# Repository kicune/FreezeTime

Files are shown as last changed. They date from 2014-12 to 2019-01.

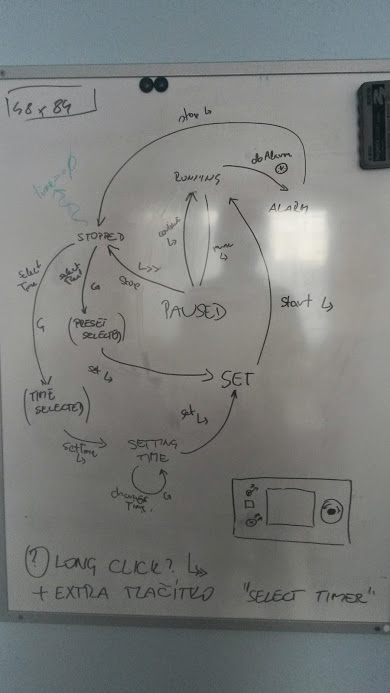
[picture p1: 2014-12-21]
FreezeTime_stateDiag.jpg

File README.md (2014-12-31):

FreezeTime
==========

Arduino - based kitchen multi timer.

This is a simple project I started to provide our kitchen with the ability to track two (but, in a theory, with many more!) kitchen timers running simultaneously. You know, to satistfy your coffee brewing needs, when your SO is busy timing the dinner or what not.

My first approach was to buy another kitchen timer, but after some thought I decided that would be seriously uncool.
This is the second approach. :)

Some basic info:
- the schema utilizes LCD display from Nokia 5110. It's very cheap, it's very bright and easy to work with. But beware - it runs on 3V only, so if you try to reprogramm the microprocessor using USB, you MIGHT destroy it (I tried it, however, and mine survived quite a prolonged exposure to 5V). Reprogramming using external programmer (or simple 5V -> 3V level shifter) is preferred.
- the board for Eagle is 2-sided, which makes things slightly more complicated. There may be ways how to rearrange the board and make it single sided, but I wanted to have controls on the one side of the board and batteries & connector on the other side. The board is routed for a simple CNC router with 0.3 engraving V tip.
- the schematics is pretty straighforward, with microprocessor, binary encoder, LCD and switch. The only thing that is not absolutely basic here is the charge pump to sound the buzzer. I did not found a good buzzer with reasonable 3V input, so I use a simple 7660 charge pump to boost the voltage to 5V. Also, MOSFET is used to drive the buzzer, as it can sink a reasonable amount of current that would not be healthy for ATMEL / Arduino pins.
- if you decide to change the tone the buzzer beeps, beware - I encountered strange behaviour (microprocessor resetting itself...) with some frequencies.

- STL file for 3d printed enclosure will be added later.

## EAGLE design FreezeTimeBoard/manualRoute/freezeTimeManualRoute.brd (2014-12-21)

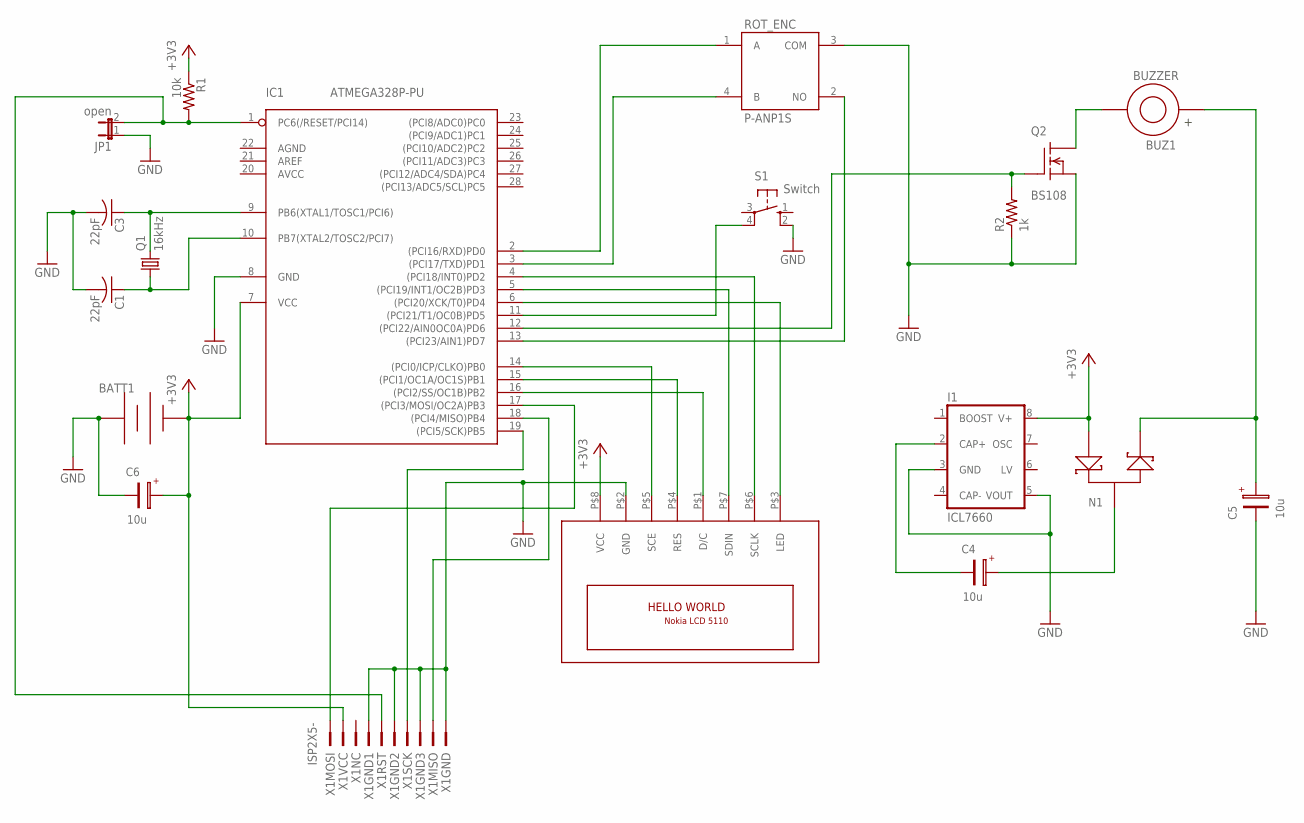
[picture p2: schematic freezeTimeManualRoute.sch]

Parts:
BATT1: 3VBATTERY; BH241-3A
BUZ1: BUZZER; AL1210MTE-P5R
C1, C3: 22pF; C1206
C4, C5, C6: 10u; C/6032-28R
I1: ICL7660; SO08
IC1: ATMEGA328P-PU; DIL28-3
JP1: open; JP1
LCD1: LCD_NOKIA5110; LCM5110_W
N1: BAT54S; SOT23
Q1: 16kHz; HC49U70
Q2: BS108; TO92-INLINE
R1: 10k; R1206
R2: 1k; R1206
ROT_ENC: P-ANP1S
S1: Switch; TACTS-24N
X1: ISP2X5-; PAK100/2500-10

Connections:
+3V3: BATT1.+, C6.+, I1.8 (V+), IC1.7 (VCC), LCD1.P$8 (VCC), N1.1, R1.1, X1.2
GND: BATT1.-, C1.2, C3.2, C5.-, C6.-, I1.3 (GND), I1.5 (VOUT), IC1.8 (GND), JP1.1, LCD1.P$2 (GND), Q2.3 (S), R2.1, ROT_ENC.3 (COM), S1.2 (S1), X1.4, X1.6, X1.8, X1.10
unnamed: C3.1, IC1.9 (PB6(XTAL1/TOSC1/PCI6)), Q1.2
unnamed: C1.1, IC1.10 (PB7(XTAL2/TOSC2/PCI7)), Q1.1
unnamed: IC1.13 ((PCI23/AIN1)PD7), ROT_ENC.2 (NO)
unnamed: IC1.1 (PC6(/RESET/PCI14)), JP1.2, R1.2, X1.5
unnamed: IC1.2 ((PCI16/RXD)PD0), ROT_ENC.1 (A)
unnamed: IC1.18 ((PCI4/MISO)PB4), X1.9
unnamed: IC1.3 ((PCI17/TXD)PD1), ROT_ENC.4 (B)
unnamed: IC1.15 ((PCI1/OC1A/OC1S)PB1), LCD1.P$4 (RES)
unnamed: IC1.14 ((PCI0/ICP/CLKO)PB0), LCD1.P$5 (SCE)
unnamed: IC1.16 ((PCI2/SS/OC1B)PB2), LCD1.P$1 (D/C)
unnamed: IC1.17 ((PCI3/MOSI/OC2A)PB3), X1.1
unnamed: IC1.11 ((PCI21/T1/OC0B)PD5), S1.4 (P1)
unnamed: IC1.6 ((PCI20/XCK/T0)PD4), LCD1.P$3 (LED)
unnamed: BUZ1.2, Q2.1 (D)
unnamed: IC1.19 ((PCI5/SCK)PB5), X1.7
unnamed: IC1.12 ((PCI22/AIN0OC0A)PD6), Q2.2 (G), R2.2
unnamed: IC1.5 ((PCI19/INT1/OC2B)PD3), LCD1.P$7 (SDIN)
unnamed: IC1.4 ((PCI18/INT0)PD2), LCD1.P$6 (SCLK)
unnamed: C4.-, I1.2 (CAP+)
unnamed: C4.+, N1.3
unnamed: BUZ1.1 (+), C5.+, N1.2

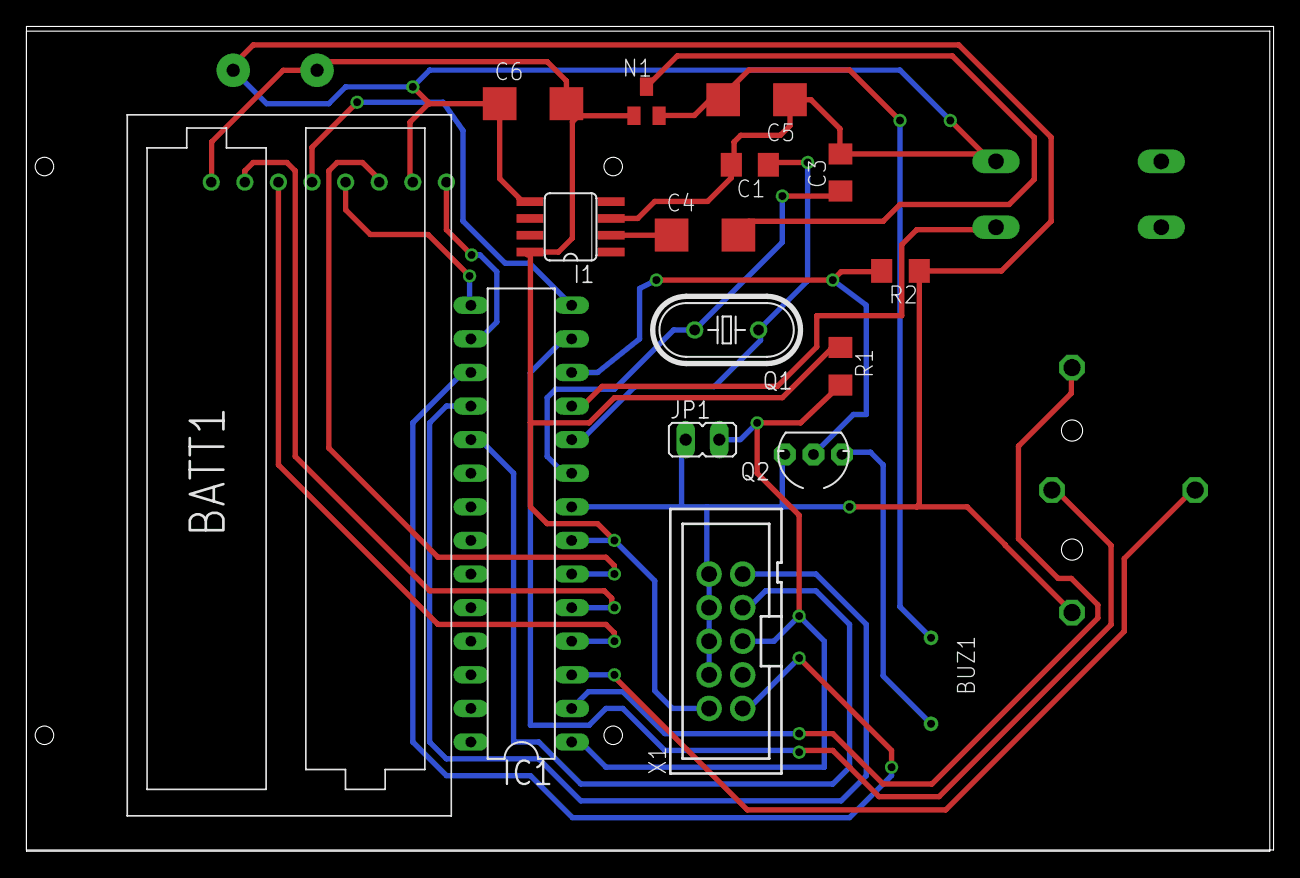
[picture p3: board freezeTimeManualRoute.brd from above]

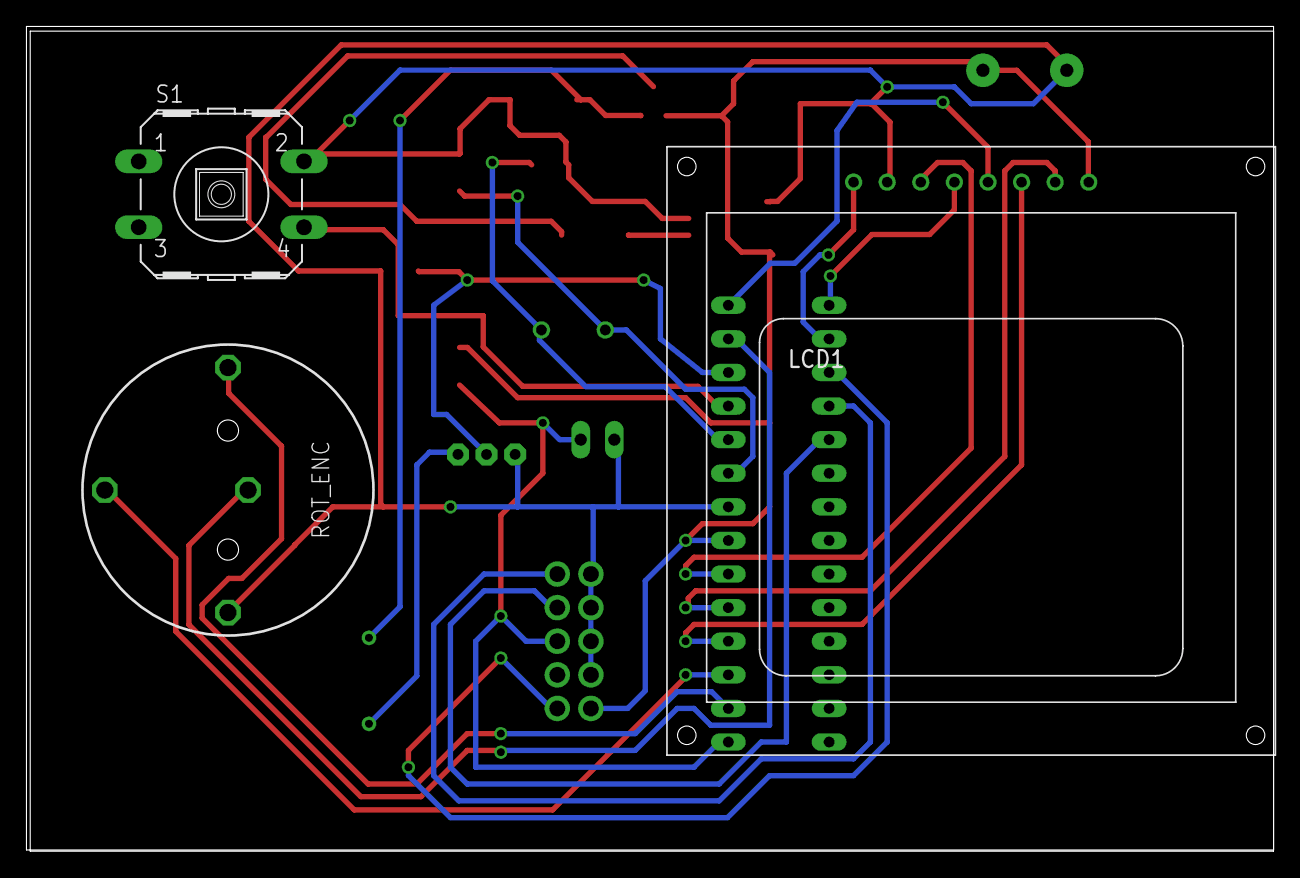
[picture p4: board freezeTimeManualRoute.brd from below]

Board: 2 copper layers, 94.3 x 62.3 mm, 19 parts (3 on the bottom side), 23 nets.

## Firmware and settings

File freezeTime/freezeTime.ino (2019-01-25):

#include <U8glib.h>
#include <Encoder.h>
#include <OneButton.h>
//#include <SoftwareSerial.h>
#include "freezeTimer.h"
#include "pitches.h"
#include "Ports.h"

/*
*    Zapojeni:
 *    
 *    Display: VSS:GND, VDD:+5V , RS:10, R/W:11, E:13, PSB:GND, A:+5V, K:GND
 *    Encoder: A:2, B:3, COM:GND, N0:7
 *    Beeper: -:GND, S:12
 *    Prepinac timeru: -:GND, S:8
 *    
 */

#define ENC_PIN_A    2
#define ENC_PIN_B    3
#define ENC_PIN_SWITCH    7
#define BEEP_PIN     6
#define SWITCH_PIN   5

#define SCK_PIN      13
#define LCD_LED_PIN  4

//U8GLIB_ST7920_128X64_1X u8g(SCK_PIN);

//5110 hw SPI: U8GLIB_PCD8544(sck, mosi, cs, a0 [, reset])
//5110 sw SPI: U8GLIB_PCD8544(cs, a0 [, reset])
//led sck mosi d/c(a0) rst sce(c/s) gnd vcc
//U8GLIB_PCD8544 u8g(12, 11, 8, 10, 9);
U8GLIB_PCD8544 u8g(0, 1, 8, 10, 9); 

#define NUM_OF_TIMERS    2
FreezeTimer timers[] = {            //an array of timers
    FreezeTimer("Timer 1", 0, 0, 0, &u8g),
    FreezeTimer("Timer 2", 0, 0, TIMER_HEIGHT, &u8g)
 };


//variables and defines to process encoder clicks
#define ENC_CLICKED  1
#define ENC_PRESSED  2
//#define ENC_PRESS_DELAY    500    // how long must the long press be, in ms.

//how long timer stays on when nothing is happening (in ms.)
#define TIMER_OFF_DELAY    10000

//pause between two alarm beeps, in millis.
#define ALARM_PAUSE    500

byte encoderClicked = 0;
byte risingFalling = 0;  
boolean isDisplayOn = false;

FreezeTimer *activeTimer = NULL;     //a pointer to the timer that currently receives an input
byte activeTimerIdx;

char buf[24];

Encoder encoder(ENC_PIN_A, ENC_PIN_B);
long encPrevValue = 0;
long encValue = 0;

OneButton btnSwitch(SWITCH_PIN, true);      //Switch timer button
OneButton btnEncoder(ENC_PIN_SWITCH, true); //encoder button

//timestamp of the last press
unsigned long lastActivityTimestamp = 0;
//sleeping flag
boolean isSleeping = false;

void draw(void) {
    u8g.setColorIndex(1);
    u8g.drawFrame(0,0,84, 48);
//    u8g.setFont(u8g_font_unifont);  
    u8g.setFont(u8g_font_7x13B);
    u8g.setFontRefHeightExtendedText();
    u8g.setFontPosTop();    
}

//put the FreezeTimer to sleep
void sleep() {
     //turn the lcd light off
    displayOff();
    //put the display to sleep
    u8g.sleepOff();
    //put ATMEL to sleep
    Sleepy::powerDown();    
}

void wakeUp() {
    //ATMEL will wake up itself with an interrupt
    //wake the display
    u8g.sleepOn();
    displayOn();
    
}

void displayOn() {
    digitalWrite(LCD_LED_PIN, 1);
    isDisplayOn = true;
}

void displayOff() {
    digitalWrite(LCD_LED_PIN, 0);
    isDisplayOn = false;
}

void timerSwitch() {
    lastActivityTimestamp = millis();
    //if the lcd backlight is off, turn it on
    if(!isDisplayOn) displayOn();
    
    //deactivate current timer
    activeTimer->setActive(false);
    
    //switch to the next timer
    if(++activeTimerIdx > NUM_OF_TIMERS - 1) {
        activeTimerIdx = 0;
    }   
    
    //activate the next timer
    activeTimer = &timers[activeTimerIdx];
    activeTimer->setActive(true);
}

void encoderClick() {
    //confirm click by beeping
    tone(BEEP_PIN, NOTE_C4, 70);
    //if the lcd backlight is off, turn it on
    if(!isDisplayOn) displayOn();
    
    lastActivityTimestamp = millis();
    
    activeTimer->click();    
}

void encoderPress() {
    //confirm click by long beep
    tone(BEEP_PIN, NOTE_C4, 210);
    lastActivityTimestamp = millis();
    activeTimer->longClick();
}

void soundAlarm() {
    static unsigned long lastAlarmMillis = 0; //timestamp of the last alarm sounding

    //sound the alarm - verify the delay since the last alarm sound and if it's bigger than the ALARM_PAUSE, sound the beeper
    if(millis() - lastAlarmMillis > ALARM_PAUSE) {
        tone(BEEP_PIN, NOTE_C5, 100);
        lastAlarmMillis = millis();
        //delay(100);
    }
}

void initialiseInterrupt() {
    // PCICR |= (1 << PCIE2);
    // PCMSK2 |= (1 << PCINT21);
    // PCMSK2 |= (1 << PCINT23);  
    
  cli();		// switch interrupts off while messing with their settings  
  
  //arduino: 5 atmel: 11 - PCINT21
  //arduino: 7 atmel: 13 - PCINT23
  PCICR =0x04;          // Enable PCINT2interrupt
//  PCMSK1 = 0b00101000;  //Pins 11 and 13 (5 and 7 on arduino)
  PCMSK2 = 0b10100000;  //interrupt pins 21 and 23 (5 and 7 on arduino)
  sei();		// turn interrupts back on
}

//ISR(PCINT2_vect) {    // Interrupt service routine. Every single PCINT8..14 (=ADC0..5) change
            // will generate an interrupt: but this will always be the same interrupt routine
//    tone(BEEP_PIN, NOTE_E4, 100);
//}

void setup(void) {
    //Serial.begin(9600);
    tone(BEEP_PIN, NOTE_C4, 100);
    delay(200);    
    tone(BEEP_PIN, NOTE_C4, 100);    
 
    u8g.setColorIndex(1);
    u8g.setRot180();

    //set LCD_LED_PIN to output
    pinMode(LCD_LED_PIN, OUTPUT);
    displayOn();
    
    activeTimerIdx = 0;
    activeTimer = &timers[activeTimerIdx];
    activeTimer->setActive(true);
    
    lastActivityTimestamp = millis();
    
    //attach handler to timer switch button
    btnSwitch.attachClick(timerSwitch);
    //attach handler to encoder button
    btnEncoder.attachClick(encoderClick);
    //btnEncoder.attachDoubleClick(encoderDoubleClick);
    btnEncoder.attachPress(encoderPress);    
    //FIXME: enable internal pullup resistor on unused pins to save the battery
    //initialiseInterrupt();
}

void loop(void) {
    //process encoder change
    encValue = encoder.read();
    
    //ATMEL is waked up by any interrupt, here we wake up also the display
    if(isSleeping) {
        tone(BEEP_PIN, NOTE_C4, 100);
        wakeUp();
        isSleeping = false;
        lastActivityTimestamp = millis();
    }
    
    int clickDiff = (encValue - encPrevValue) / 2; //encoder changes 2 values per click
    if(clickDiff != 0) { 
        lastActivityTimestamp = millis();
        //if the lcd backlight is off, turn it on
        if(!isDisplayOn) displayOn();
        if(clickDiff > 0) {
            //Serial.println("Turned Left");  
            while(clickDiff > 0) {
                activeTimer->getTimerState()->turnLeft();
                clickDiff--;;
            }
        } 
        else {
            //Serial.println("Turned Right");              
            while(clickDiff < 0 ) {
                activeTimer->getTimerState()->turnRight();
                clickDiff++;            
            }
        }  
        encPrevValue = encValue  + (encValue - encPrevValue) % 2;
    }
        
    //process buttons:
    //timer switch
    btnSwitch.tick();
    //encoder button
    btnEncoder.tick();
    
    //update timers
    boolean isAllStopped = true;
    for(int f = 0; f < NUM_OF_TIMERS; f++) {
        //auto-off: check if all timers are in STOPPED state
        if(timers[f].getTimerState() != &timers[f].stoppedState)
            isAllStopped = false;
            
        timers[f].updateTimer();
    }
    
    //if the last activity happened before TIMER_OFF_DELAY msec...
    if(millis() - lastActivityTimestamp > TIMER_OFF_DELAY) {
        if(isAllStopped) {
            //if all timers are stopped, put timer to sleep 
            sleep();
            isSleeping = true;
        } else {
          //if there are some timers running, just turn off the backlight
          displayOff();
        }
    }

    
    
    //is alarm active for any of the timers? if yes, sound the alarm
    for(int f = 0; f < NUM_OF_TIMERS; f++) {
        if(timers[f].getTimerState() == &timers[f].alarmState) {
            //if the focus is on an inactive alarm, switch to the active one
            if(!timers[f].getActive()) {
              timerSwitch();
            }
            soundAlarm();
            //and skip the rest - multiple beeps causes problems
            break;
        }
    }

    //process state-specific actions:
    for(int f = 0; f < NUM_OF_TIMERS; f++) {
      timers[f].getTimerState()->process();
    }

    // picture loop
    u8g.firstPage();  
    do {
        draw();
        for(int f = 0; f < NUM_OF_TIMERS; f++) {
            timers[f].draw();
        }
    } 
    while(u8g.nextPage());

}

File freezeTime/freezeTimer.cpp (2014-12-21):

#include "freezeTimer.h"
#include "stoppedState.h"


//******* Static members ************
#define COUNT_PRESETS   5

Preset FreezeTimer::presets[] = {
  {"Custom", 0},    
  {"Kafe", 210},
  {"Chleb1", 600},
  {"Chleb2", 2100},
  {"Pasta", 180}
};

char* formatTime(char *buffer, long milliTime) {
    unsigned int minutes = milliTime / 60000L;
    unsigned int seconds = (milliTime / 1000L) % 60L;
    sprintf(buffer, "%02d:%02d", minutes, seconds);
    return buffer;
}

/************************************/

FreezeTimer::FreezeTimer(const char* name, unsigned long time, unsigned int x, unsigned int y, U8GLIB *display) : 
  xPos(x), yPos(y), timerName(name), initialTime(time), p_u8g(display), isActive(false),
  stoppedState(this), runningState(this), pausedState(this), alarmState(this), minuteSettingState(this), secondSettingState(this)
{
    
    timerState = &stoppedState;
    selPresetIdx = 0;
}

void FreezeTimer::draw() {
  
  //highlight timer if active   
  if(isActive) {
    p_u8g->setColorIndex(1);
    p_u8g->drawBox(xPos, yPos, TIMER_WIDTH, TIMER_HEIGHT);
  }
  
  //let active state do its drawing
  timerState->draw();  
}

Preset* FreezeTimer::getSelectedPreset()
{
    return &FreezeTimer::presets[selPresetIdx];
}

const char* FreezeTimer::getName()
{
  return timerName;
}

void FreezeTimer::setNextPreset()
{
  if(selPresetIdx < COUNT_PRESETS -  1)
    ++selPresetIdx;
  else
    selPresetIdx = 0;
}

void FreezeTimer::setPreviousPreset()
{
  if(selPresetIdx > 0)
    --selPresetIdx;
  else
    selPresetIdx = COUNT_PRESETS - 1;  
}

TimerState* FreezeTimer::getTimerState()
{
    return timerState;
}

void FreezeTimer::setTimerState(TimerState *state)
{
    timerState = state;
}

void FreezeTimer::startTimer()
{
    setTimerState(&runningState);
    remainingMillis = initialTime;
    lastMillis = millis();
    Serial.print("Timer started: ");
}

void FreezeTimer::pauseTimer()
{
    setTimerState(&pausedState);
}

void FreezeTimer::unpauseTimer()
{
    setTimerState(&runningState);
    //reset lastMillis so the time spent on pause is not counted against remaining timer time
    lastMillis = millis();
}

void FreezeTimer::stopTimer()
{
    setTimerState(&stoppedState);
   
}

void FreezeTimer::updateTimer()
{
    unsigned long actualMillis = millis();    
    //timer is updated only if the timer is running
    if(timerState == &runningState) {
        remainingMillis = remainingMillis - (actualMillis - lastMillis);
        //Serial.print("Remaining millis: "); Serial.println(remainingMillis);            
        if(remainingMillis < 0) {
            //Serial.print("Start millis: "); Serial.println(startMillis);            
            //Serial.print("Actual millis: "); Serial.println(actualMillis);
            fireAlarm();
        }
        lastMillis = actualMillis;
    }
    

}

long FreezeTimer::getRemainingMillis()
{
    return remainingMillis;
}

void FreezeTimer::fireAlarm() 
{
    setTimerState( &alarmState );
}

void FreezeTimer::muteAlarm()
{
    //by switching the state to stoppedState the alarm will be muted
    stopTimer();
}

U8GLIB* FreezeTimer::getDisplay()
{
    return p_u8g;
}

unsigned int FreezeTimer::getX() {
    return xPos;
}

unsigned int FreezeTimer::getY() {
    return yPos;
}

void FreezeTimer::setActive(boolean active) {
    isActive = active;
}

boolean FreezeTimer::getActive() {
    return isActive;
}

unsigned long FreezeTimer::getInitialTime() {
    return initialTime;
}

void FreezeTimer::setInitialTime(unsigned long initial) {
    initialTime = initial;
}

char* FreezeTimer::getActualStrTime() {
    unsigned long remainingSeconds = getRemainingMillis() / 1000;
    unsigned int minutes = remainingSeconds / 60;
    unsigned int seconds = remainingSeconds % 60;
    sprintf(strTimeBuffer, "%02d:%02d", minutes, seconds);
    return strTimeBuffer;
}

void FreezeTimer::click() {
    //just pass the click to the active state
    if(timerState != NULL)
        timerState->click();
}

void FreezeTimer::longClick() { 
    //just pass the click to the active state
    if(timerState != NULL)
        timerState->longClick();
}


void FreezeTimer::displayPresetName() {
    const char nullName[] = "No preset";
    const char *presName;
    
    Preset *_pres = getSelectedPreset();
    if(_pres == NULL) {
        presName = nullName;
    } else {
        presName = getSelectedPreset()->name;
    }

    p_u8g->drawStr(getX() + TEXT_X_OFFSET, getY() + TEXT_Y_OFFSET, presName);
}

void FreezeTimer::displayTimerTime(char* strTime) {

    
    //time is justified to the right
    byte h = p_u8g->getFontAscent() - p_u8g->getFontDescent();  
    byte w = p_u8g->getStrWidth(strTime);
    byte pX = getX() + TIME_X_OFFSET;
    byte pY = getY() + TEXT_Y_OFFSET;    
    
    
    //print the remaining time 
    p_u8g->drawStr(pX - w, pY, strTime);    

}

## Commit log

2014-12-21 Added the Eagle board schematics.
    [freezeTime.brd, freezeTime.sch, freezeTimeManualRoute.brd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]
2014-12-31 Modified functionality for switching off the LED display while the timers run to save the batteries. LCD is lit up on interrupt.
2014-12-31 Removed backups of routed boards & fixed .gitignore to really ignore them
2016-01-03 - when the alarm is on and the focus is on an inactive alarm, switch to the active one - check the timeout during minute and second custom setting - when there is more than 15 seconds of inactivity, 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
2019-01-25 Display rotated to accomodate the new PCB
